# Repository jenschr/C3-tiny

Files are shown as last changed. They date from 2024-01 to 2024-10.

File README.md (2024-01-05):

# ESP32 C3-tiny
A Tiny but very functional DevBoard with Temperature/Moisture sensor and 5 programmable LEDs.

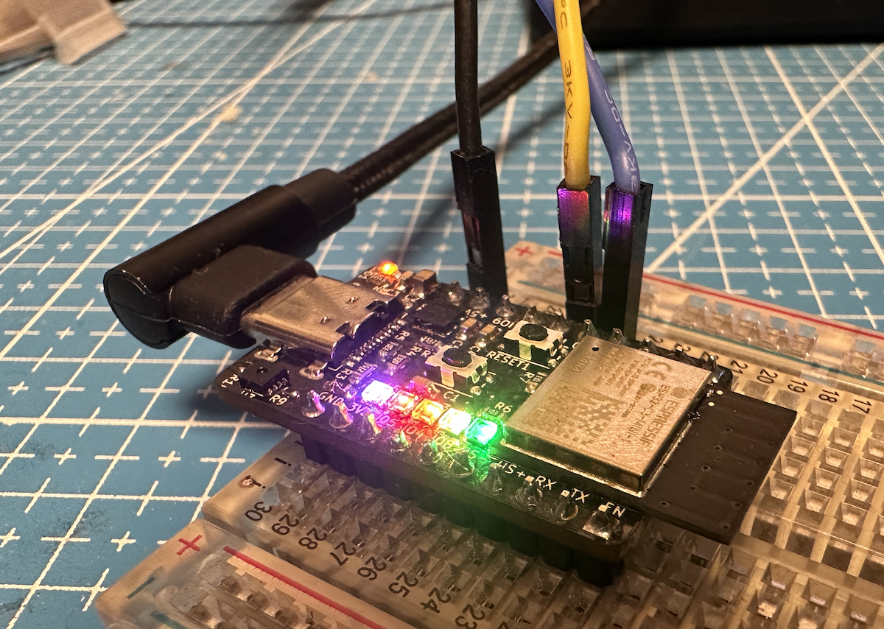
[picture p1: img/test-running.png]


## Why smaller?

The official devboard from Espressif is crazy big for such a tiny module? I wanted to make something that leaves two rows on each side when put into a normal half-size breadboard, while testing out the Espressif ESP32 C3 module. Also - I could make this as a christmas gift for my son since he studies electronics and likes RiscV? And then I could publish it as a starting point for others to design their own boards? Why not!

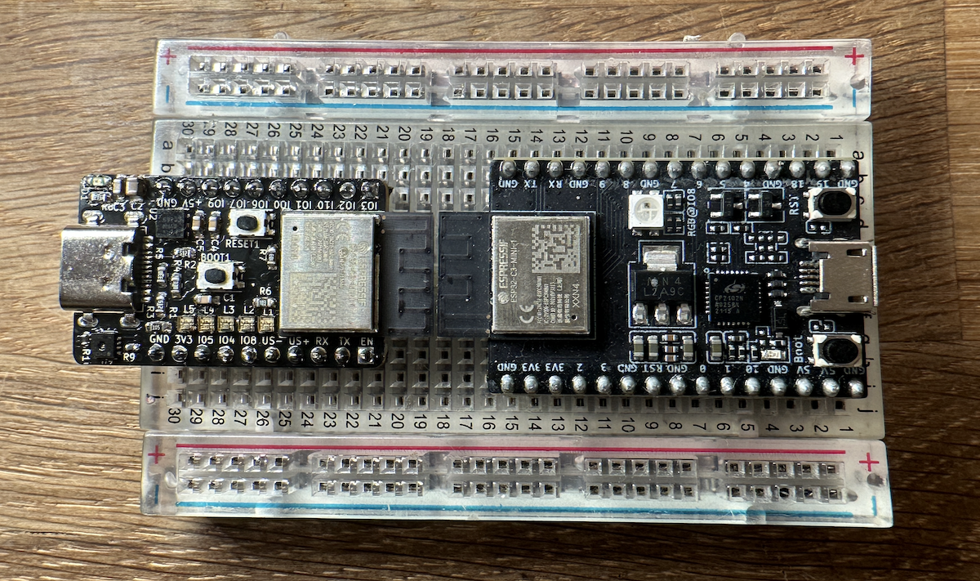
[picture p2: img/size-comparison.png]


I won't say that the pinout isn't a bit messy (as not in correct order), but all pins are broken out and this project should make it easy for anyone to create their own Espressif C3 based boards. The repository is complete with [Kicad files](pcb/), [BOM](bom/) and [test code for Arduino](code/).

## Pinout

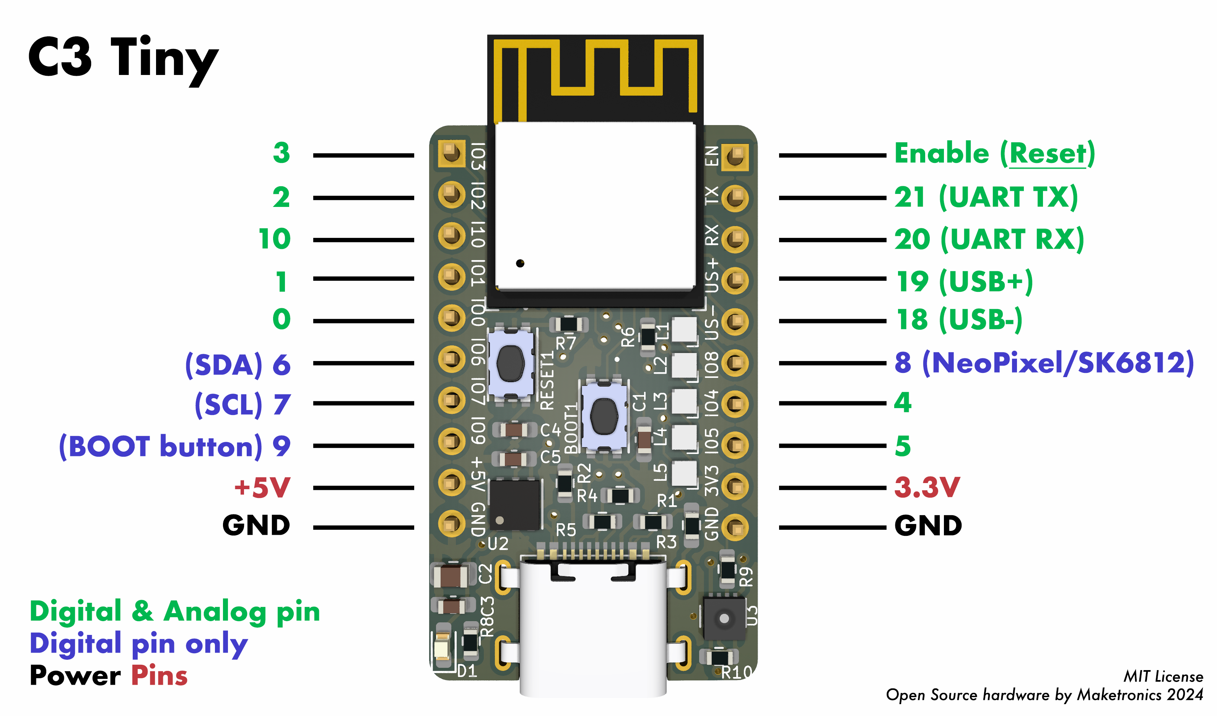
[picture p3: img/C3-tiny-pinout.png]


[*] All the module pins are broken out and some pins such as pin 18 + 19 is used for the USB connection. That means that you cannot connect anything to these if you want to use USB.

[*] You also cannot use pins 6 (SDA) and 7 (SCL) for other things if you want to also use the SHT31 sensor connected to these pins (I2C Bus). Other I2C devices shopuld also be connected to these pins. Note that there are pullup resistors on these pins. If you keep this in mind, you can use the pins if you don't use I2C.

[*] The Boot button may be used as an input - after startup has finished.

## Arduino usage

Select "ESP32C3 Dev Module" as the board and set "USB CDC on Boot" to true. The SHT31 sensor is on address 0x44 and you need to start I2C using pins 6 and 7 like this:

`Wire.begin(6,7);`

The five RGB LEDs are connected to pin 8. Check out the code example for details.

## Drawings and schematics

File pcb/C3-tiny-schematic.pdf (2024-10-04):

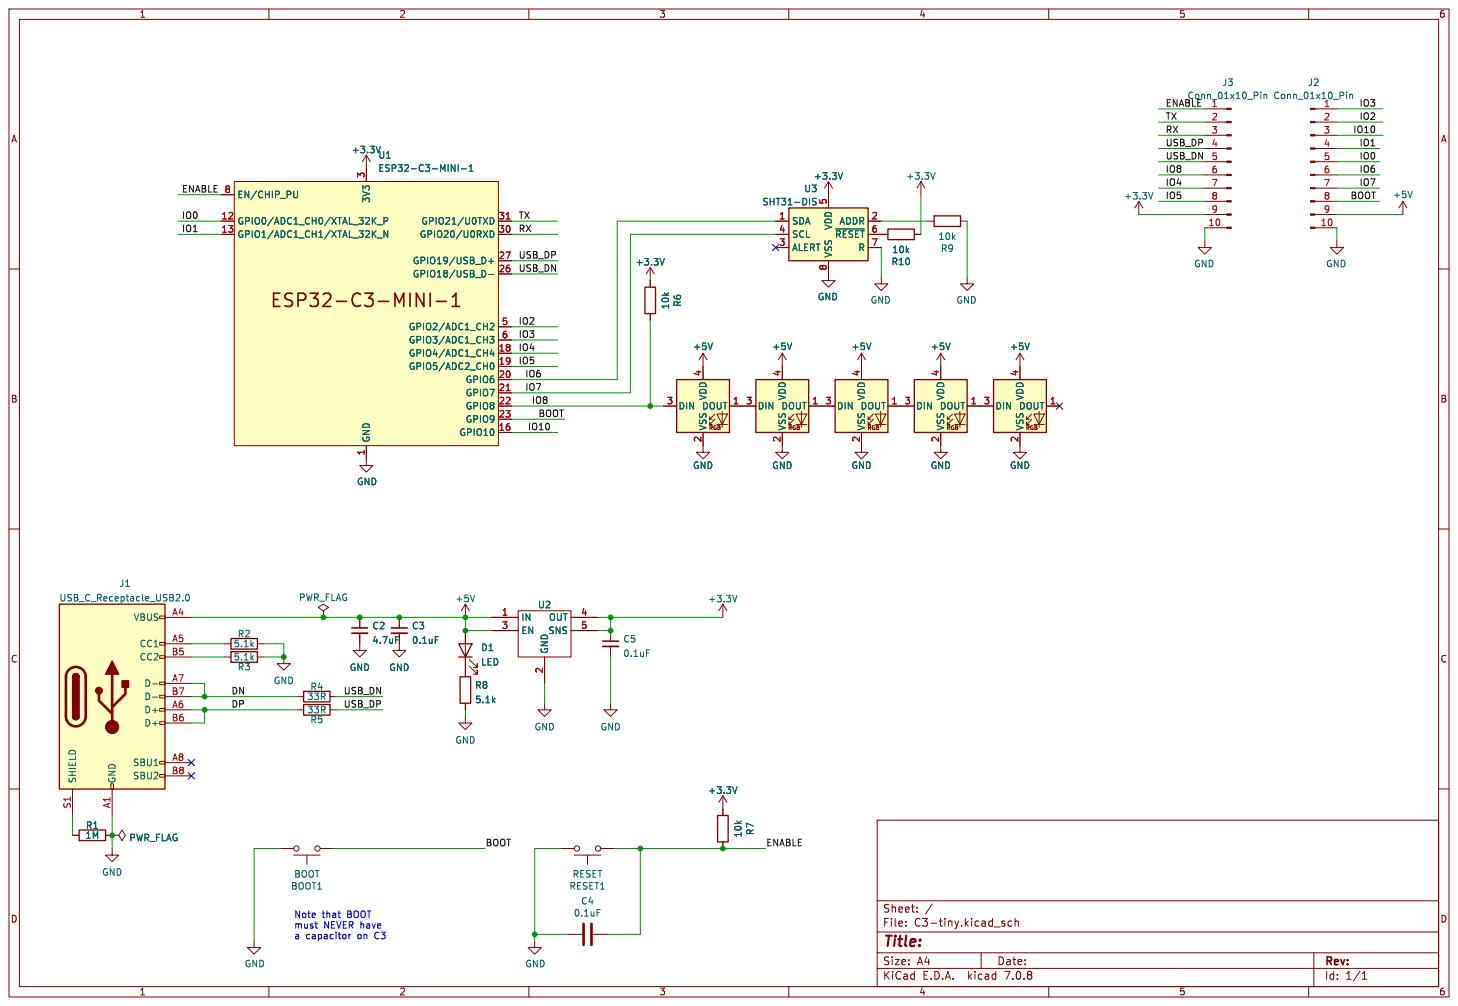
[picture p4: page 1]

Id: 1/1 Title: File: C3-tiny.kicad_sch Sheet: / 10k R6 +3.3V C2

BOOT Note that BOOT must NEVER have

2 EN 3 OUT 4 SNS 5 U2 GND

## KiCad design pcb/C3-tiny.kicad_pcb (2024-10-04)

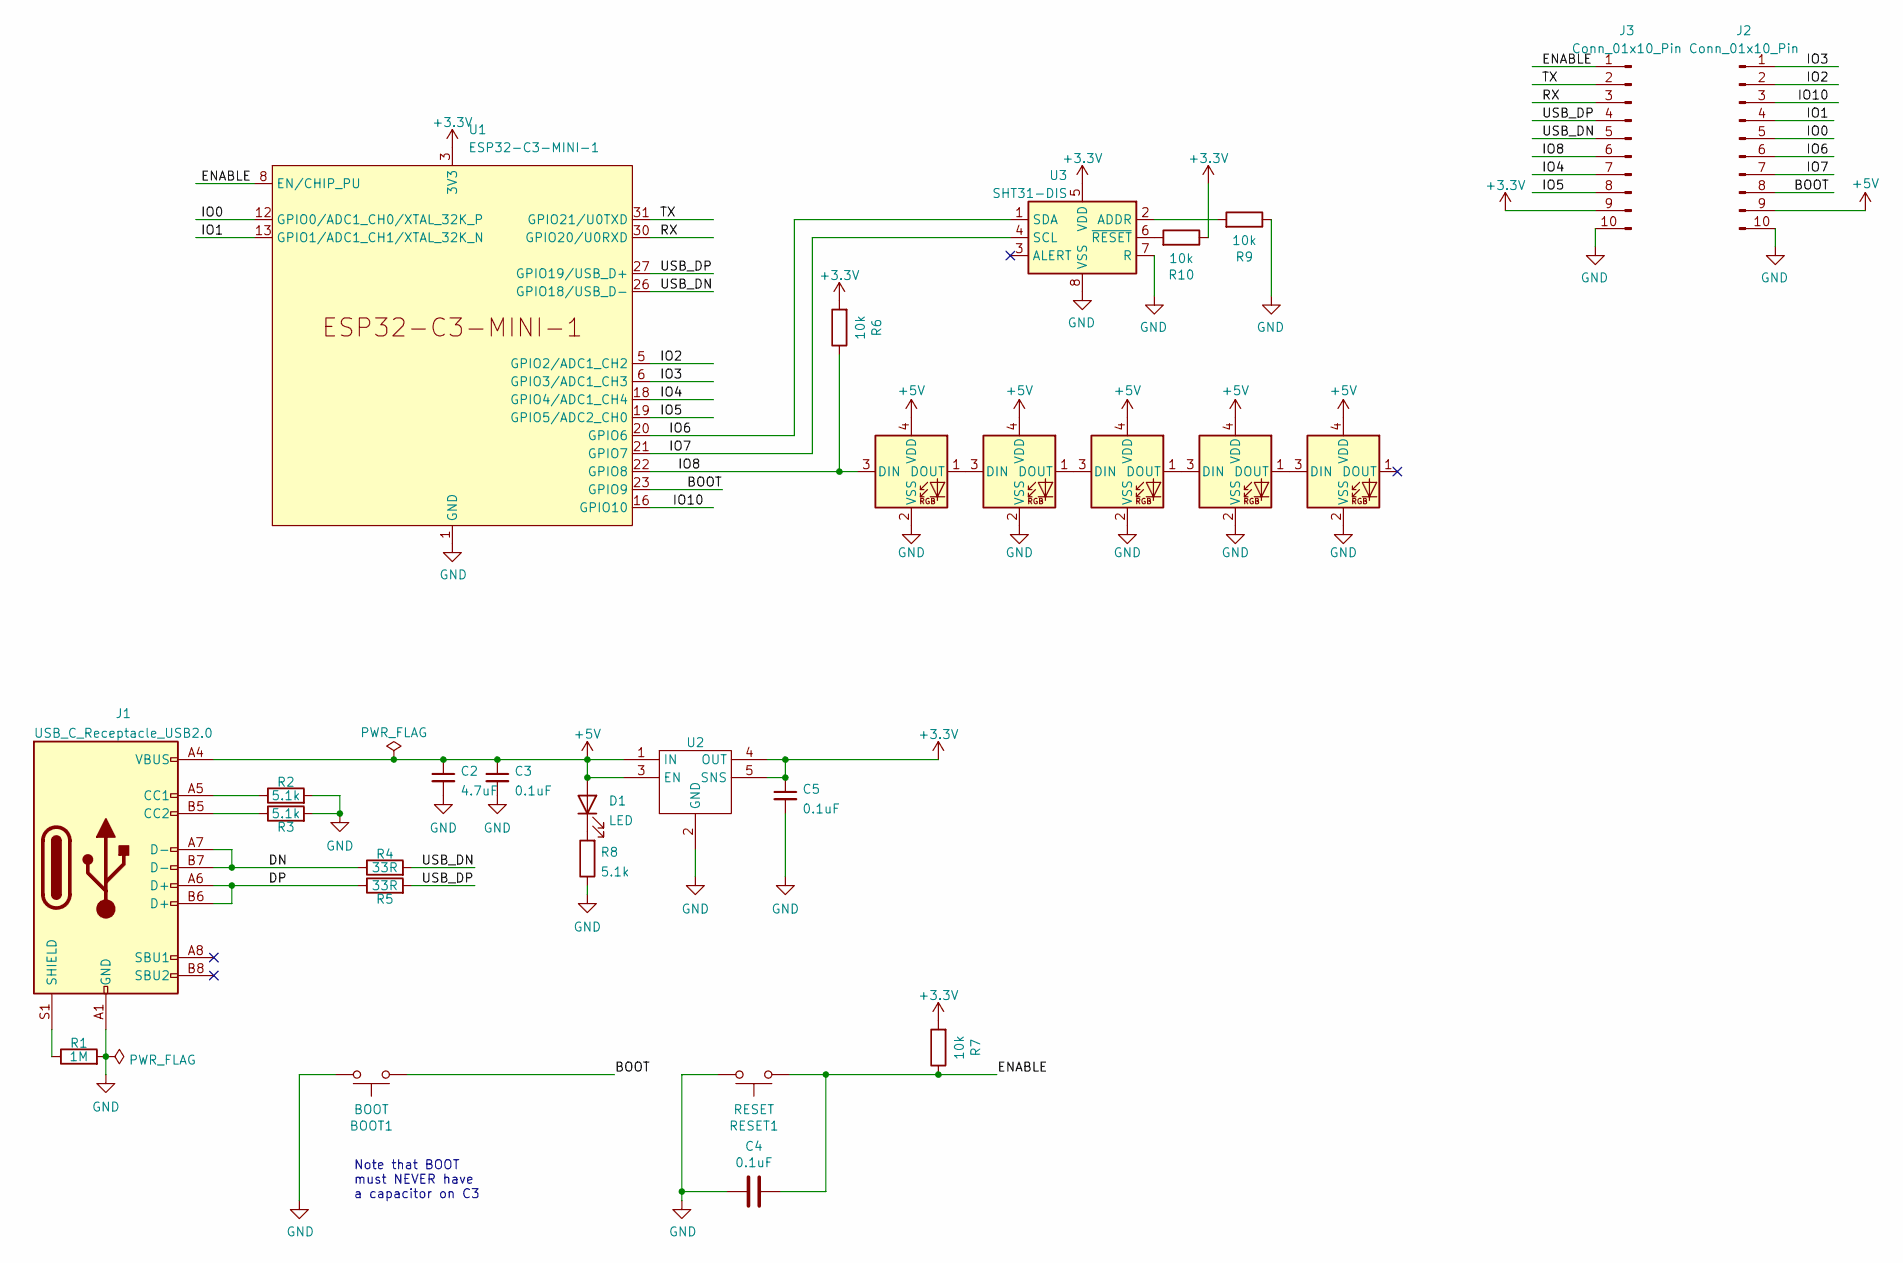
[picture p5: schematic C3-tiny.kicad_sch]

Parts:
BOOT1: BOOT; KMR241GLFS; MPN KMR241GLFS
C2: 4.7uF; C_0805_2012Metric
C3, C4, C5: 0.1uF; C_0603_1608Metric_Pad1.08x0.95mm_HandSolder
D1: LED; LED_0603_1608Metric_Pad1.05x0.95mm_HandSolder
J1: USB_C_Receptacle_USB2.0; TYPE-C-31-M-14
J2, J3: Conn_01x10_Pin; PinHeader_1x10_P2.54mm_Vertical
L1, L2, L3, L4, L5: SK6812MINI; LED_SK6812_EC15_1.5x1.5mm
R1: 1M; R_0603_1608Metric_Pad0.98x0.95mm_HandSolder
R2, R3, R8: 5.1k; R_0603_1608Metric
R4, R5: 33R; R_0603_1608Metric
R6, R7, R9, R10: 10k; R_0603_1608Metric; MPN RMCF0603JG10K0
RESET1: RESET; KMR241GLFS; MPN KMR241GLFS
U1: ESP32-C3-MINI-1
U2: NCP692MN33T2G; DFN-6-1EP_3x3mm_P0.95mm_EP1.7x2.6mm
U3: SHT31-DIS; Sensirion_DFN-8-1EP_2.5x2.5mm_P0.5mm_EP1.1x1.7mm; MPN SHT31-DIS

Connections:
+3.3V: C5.1, J3.9, R6.2, R7.2, R10.1, U1.3 (3V3), U2.4 (OUT), U2.5 (SNS), U3.5 (VDD)
+5V: C2.1, C3.1, D1.2 (A), J1.A4 (VBUS), J1.A9 (VBUS), J1.B4 (VBUS), J1.B9 (VBUS), J2.9, L1.4 (VDD), L2.4 (VDD), L3.4 (VDD), L4.4 (VDD), L5.4 (VDD), U2.1 (IN), U2.3 (EN), U2.6 (IN)
/BOOT: BOOT1.1, J2.8, U1.23 (GPIO9)
/DN: J1.A7 (D-), J1.B7 (D-), R4.1
/DP: J1.A6 (D+), J1.B6 (D+), R5.1
/ENABLE: C4.1, J3.1, R7.1, RESET1.1, U1.8 (EN/CHIP_PU)
/IO0: J2.5, U1.12 (GPIO0/ADC1_CH0/XTAL_32K_P)
/IO1: J2.4, U1.13 (GPIO1/ADC1_CH1/XTAL_32K_N)
/IO2: J2.2, U1.5 (GPIO2/ADC1_CH2)
/IO3: J2.1, U1.6 (GPIO3/ADC1_CH3)
/IO4: J3.7, U1.18 (GPIO4/ADC1_CH4)
/IO5: J3.8, U1.19 (GPIO5/ADC2_CH0)
/IO6: J2.6, U1.20 (GPIO6), U3.1 (SDA)
/IO7: J2.7, U1.21 (GPIO7), U3.4 (SCL)
/IO8: J3.6, L1.3 (DIN), R6.1, U1.22 (GPIO8)
/IO10: J2.3, U1.16 (GPIO10)
/RX: J3.3, U1.30 (GPIO20/U0RXD)
/TX: J3.2, U1.31 (GPIO21/U0TXD)
/USB_DN: J3.5, R4.2, U1.26 (GPIO18/USB_D-)
/USB_DP: J3.4, R5.2, U1.27 (GPIO19/USB_D+)
GND: BOOT1.2, C2.2, C3.2, C4.2, C5.2, J1.A1 (GND), J1.A12 (GND), J1.B1 (GND), J1.B12 (GND), J2.10, J3.10, L1.2 (VSS), L2.2 (VSS), L3.2 (VSS), L4.2 (VSS), L5.2 (VSS), R1.2, R2.2, R3.2, R8.1, R9.1, RESET1.2, U1.1 (GND), U1.2 (GND), U1.11 (GND), U1.14 (GND), U1.36 (GND), U1.37 (GND), U1.38 (GND), U1.39 (GND), U1.40 (GND), U1.41 (GND), U1.42 (GND), U1.43 (GND), U1.44 (GND), U1.45 (GND), U1.46 (GND), U1.47 (GND), U1.48 (GND), U1.49 (GND), U1.50 (GND), U1.51 (GND), U1.52 (GND), U1.53 (GND), U2.2 (GND), U2.7 (GND), U3.7 (R), U3.8 (VSS), U3.9 (VSS)
unnamed: D1.1 (K), R8.2
unnamed: J1.A5 (CC1), R2.1
unnamed: J1.B5 (CC2), R3.1
unnamed: J1.S1 (SHIELD), R1.1
unnamed: L1.1 (DOUT), L2.3 (DIN)
unnamed: L2.1 (DOUT), L3.3 (DIN)
unnamed: L3.1 (DOUT), L4.3 (DIN)
unnamed: L4.1 (DOUT), L5.3 (DIN)
unnamed: R9.2, U3.2 (ADDR)
unnamed: R10.2, U3.6 (~RESET)

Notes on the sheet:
Note that BOOT must NEVER have a capacitor on C3

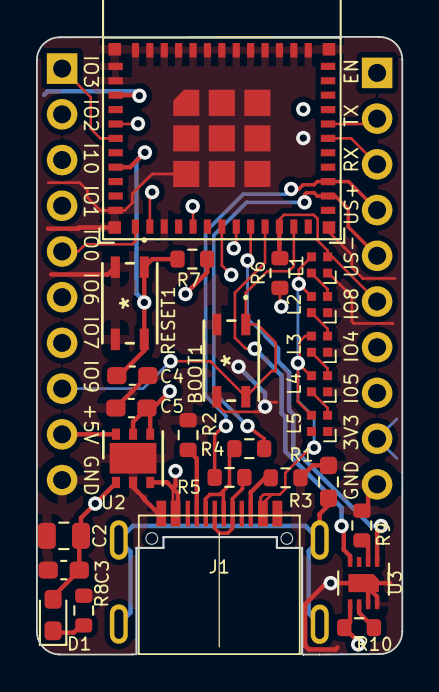
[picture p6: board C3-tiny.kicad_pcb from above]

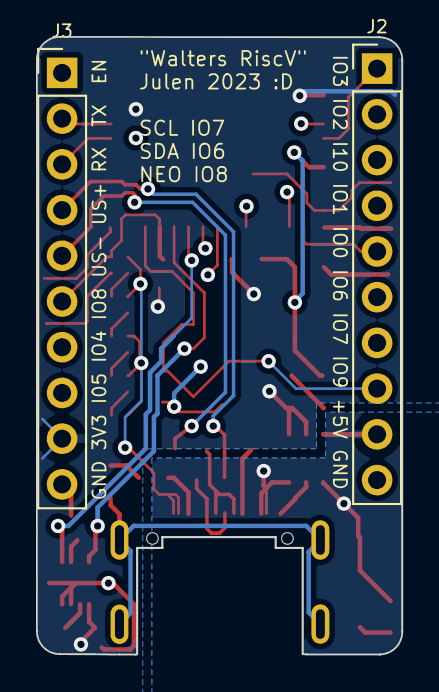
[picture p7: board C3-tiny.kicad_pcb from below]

Board: 4 copper layers, 20.3 x 34.3 mm, 28 parts (2 on the bottom side), 31 nets.

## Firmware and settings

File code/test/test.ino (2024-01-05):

#include <Adafruit_NeoPixel.h>
#include <Wire.h>
#include <SPI.h>
#include "Adafruit_SHT31.h"

Adafruit_SHT31 sht31 = Adafruit_SHT31();

#define LED_PIN   8
#define LED_COUNT 8

// Argument 1 = Number of pixels in NeoPixel strip
// Argument 2 = Arduino pin number (most are valid)
// Argument 3 = Pixel type flags, add together as needed:
//   NEO_KHZ800  800 KHz bitstream (most NeoPixel products w/WS2812 LEDs)
//   NEO_KHZ400  400 KHz (classic 'v1' (not v2) FLORA pixels, WS2811 drivers)
//   NEO_GRB     Pixels are wired for GRB bitstream (most NeoPixel products)
//   NEO_RGB     Pixels are wired for RGB bitstream (v1 FLORA pixels, not v2)
//   NEO_RGBW    Pixels are wired for RGBW bitstream (NeoPixel RGBW products)
Adafruit_NeoPixel strip(LED_COUNT, LED_PIN, NEO_RGB + NEO_KHZ800);

unsigned int nextTimeToPrintTemp = 0;

void setup() {
  Serial.begin(115200);
  strip.begin();           // INITIALIZE NeoPixel strip object (REQUIRED)
  strip.show();            // Turn OFF all pixels ASAP
  strip.setBrightness(15); // Set BRIGHTNESS to about 1/5 (max = 255)
  colorWipe(strip.Color(255,   0,   0), 50);
  delay(2000);

  Wire.begin(6,7);
  if (! sht31.begin(0x44)) {
    delay(2000);
    Serial.println("Couldn't find SHT31");
    while (1) delay(1);
  }
}


// loop() function -- runs repeatedly as long as board is on ---------------

void loop() {
  // Fill along the length of the strip in various colors...
  colorWipe(strip.Color(255,   0,   0), 50); // Red
  colorWipe(strip.Color(  0, 255,   0), 50); // Green
  colorWipe(strip.Color(  0,   0, 255), 50); // Blue
  printEnvironment();

  // Do a theater marquee effect in various colors...
  theaterChase(strip.Color(127, 127, 127), 50); // White, half brightness
  theaterChase(strip.Color(127,   0,   0), 50); // Red, half brightness
  theaterChase(strip.Color(  0,   0, 127), 50); // Blue, half brightness

  rainbow(10);             // Flowing rainbow cycle along the whole strip
  theaterChaseRainbow(50); // Rainbow-enhanced theaterChase variant
}

void printEnvironment(){
  float t = sht31.readTemperature();
  if (! isnan(t)) {  // check if 'is not a number'
    Serial.print("Temp *C = "); Serial.print(t); Serial.print("\t\t");
  } else { 
    Serial.println("Failed to read temperature");
  }
  
  float h = sht31.readHumidity();
  if (! isnan(h)) {  // check if 'is not a number'
    Serial.print("Hum. % = "); Serial.println(h);
  } else { 
    Serial.println("Failed to read humidity");
  }
}


// Some functions of our own for creating animated effects -----------------

// Fill strip pixels one after another with a color. Strip is NOT cleared
// first; anything there will be covered pixel by pixel. Pass in color
// (as a single 'packed' 32-bit value, which you can get by calling
// strip.Color(red, green, blue) as shown in the loop() function above),
// and a delay time (in milliseconds) between pixels.
void colorWipe(uint32_t color, int wait) {
  for(int i=0; i<strip.numPixels(); i++) { // For each pixel in strip...
    strip.setPixelColor(i, color);         //  Set pixel's color (in RAM)
    strip.show();                          //  Update strip to match
    delay(wait);                           //  Pause for a moment
  }
}

// Theater-marquee-style chasing lights. Pass in a color (32-bit value,
// a la strip.Color(r,g,b) as mentioned above), and a delay time (in ms)
// between frames.
void theaterChase(uint32_t color, int wait) {
  for(int a=0; a<10; a++) {  // Repeat 10 times...
    for(int b=0; b<3; b++) { //  'b' counts from 0 to 2...
      strip.clear();         //   Set all pixels in RAM to 0 (off)
      // 'c' counts up from 'b' to end of strip in steps of 3...
      for(int c=b; c<strip.numPixels(); c += 3) {
        strip.setPixelColor(c, color); // Set pixel 'c' to value 'color'
      }
      strip.show(); // Update strip with new contents
      delay(wait);  // Pause for a moment
    }
  }
}

// Rainbow cycle along whole strip. Pass delay time (in ms) between frames.
void rainbow(int wait) {
  // Hue of first pixel runs 5 complete loops through the color wheel.
  // Color wheel has a range of 65536 but it's OK if we roll over, so
  // just count from 0 to 5*65536. Adding 256 to firstPixelHue each time
  // means we'll make 5*65536/256 = 1280 passes through this loop:
  for(long firstPixelHue = 0; firstPixelHue < 5*65536; firstPixelHue += 256) {
    // strip.rainbow() can take a single argument (first pixel hue) or
    // optionally a few extras: number of rainbow repetitions (default 1),
    // saturation and value (brightness) (both 0-255, similar to the
    // ColorHSV() function, default 255), and a true/false flag for whether
    // to apply gamma correction to provide 'truer' colors (default true).
    strip.rainbow(firstPixelHue);
    // Above line is equivalent to:
    // strip.rainbow(firstPixelHue, 1, 255, 255, true);
    strip.show(); // Update strip with new contents
    delay(wait);  // Pause for a moment
  }
}

// Rainbow-enhanced theater marquee. Pass delay time (in ms) between frames.
void theaterChaseRainbow(int wait) {
  int firstPixelHue = 0;     // First pixel starts at red (hue 0)
  for(int a=0; a<30; a++) {  // Repeat 30 times...
    for(int b=0; b<3; b++) { //  'b' counts from 0 to 2...
      strip.clear();         //   Set all pixels in RAM to 0 (off)
      // 'c' counts up from 'b' to end of strip in increments of 3...
      for(int c=b; c<strip.numPixels(); c += 3) {
        // hue of pixel 'c' is offset by an amount to make one full
        // revolution of the color wheel (range 65536) along the length
        // of the strip (strip.numPixels() steps):
        int      hue   = firstPixelHue + c * 65536L / strip.numPixels();
        uint32_t color = strip.gamma32(strip.ColorHSV(hue)); // hue -> RGB
        strip.setPixelColor(c, color); // Set pixel 'c' to value 'color'
      }
      strip.show();                // Update strip with new contents
      delay(wait);                 // Pause for a moment
      firstPixelHue += 65536 / 90; // One cycle of color wheel over 90 frames
    }
  }
}

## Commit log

2024-01-05 First public version after testing
    [C3-tiny.kicad_pcb, C3-tiny.kicad_sch]
2024-10-04 Removed cap on BOOT. Cleanup some minor errors
    [C3-tiny.kicad_pcb, C3-tiny.kicad_sch]

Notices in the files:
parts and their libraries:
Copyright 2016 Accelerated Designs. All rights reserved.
